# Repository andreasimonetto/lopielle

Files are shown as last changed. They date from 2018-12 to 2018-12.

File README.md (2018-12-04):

Lopielle
========

MIDI synth based on Yamaha OPLL FM synthesis sound chip (YM2413).

Made with KiCad, MPLAB-X, Inkscape, The GIMP.

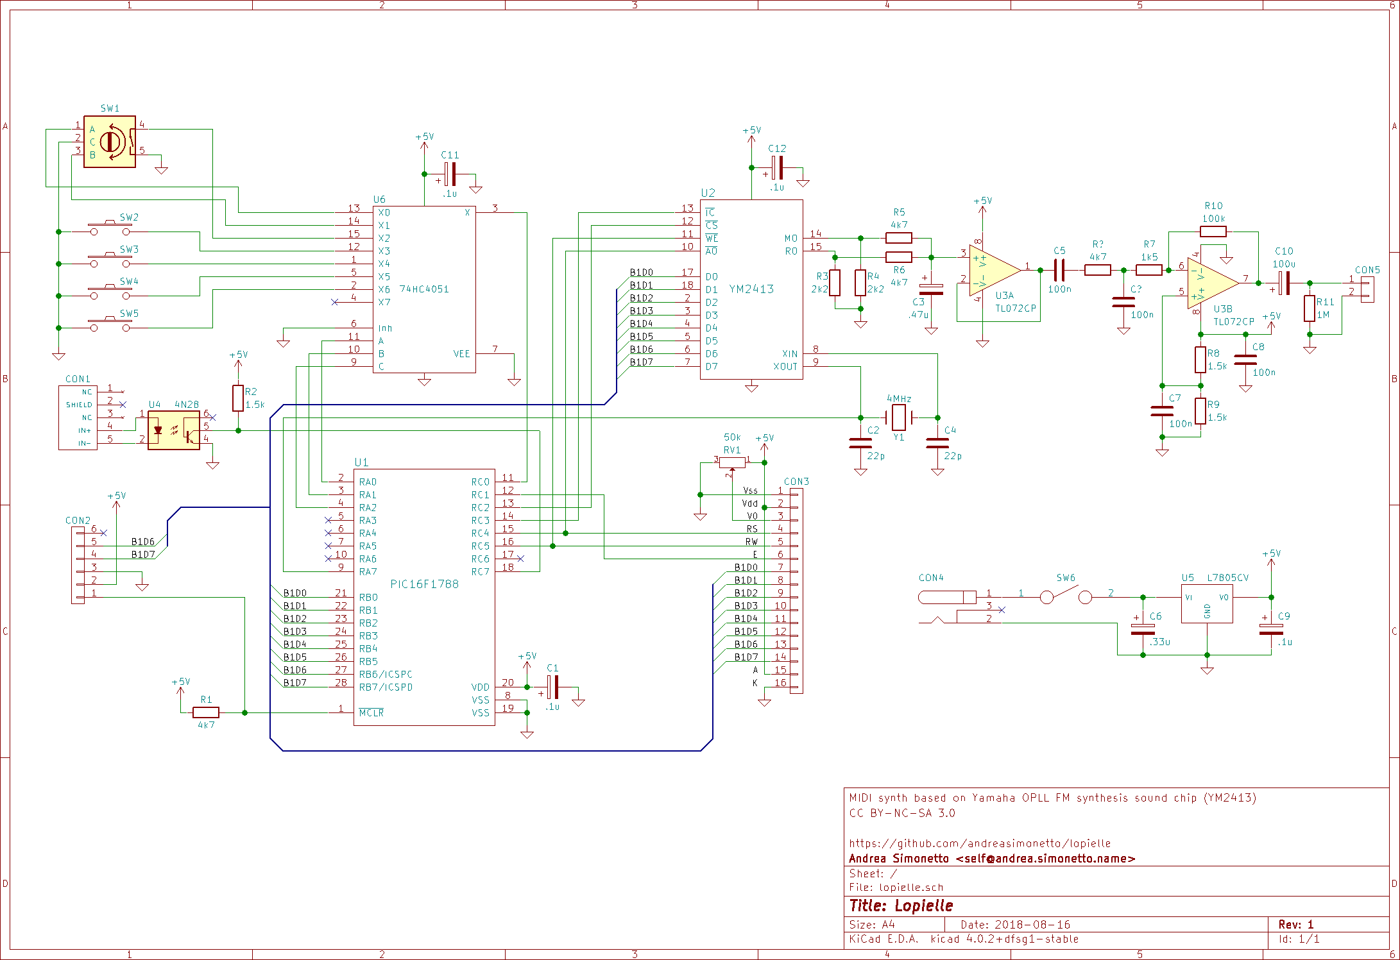
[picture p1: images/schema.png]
Electronic schematic

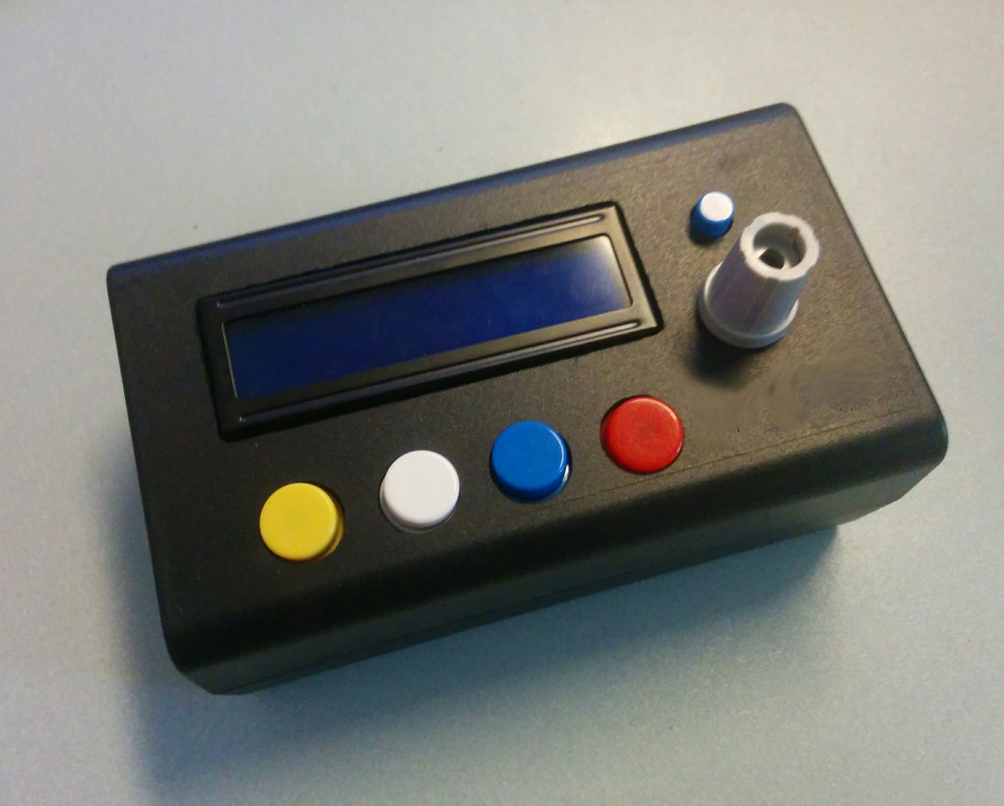
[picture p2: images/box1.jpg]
Demo product

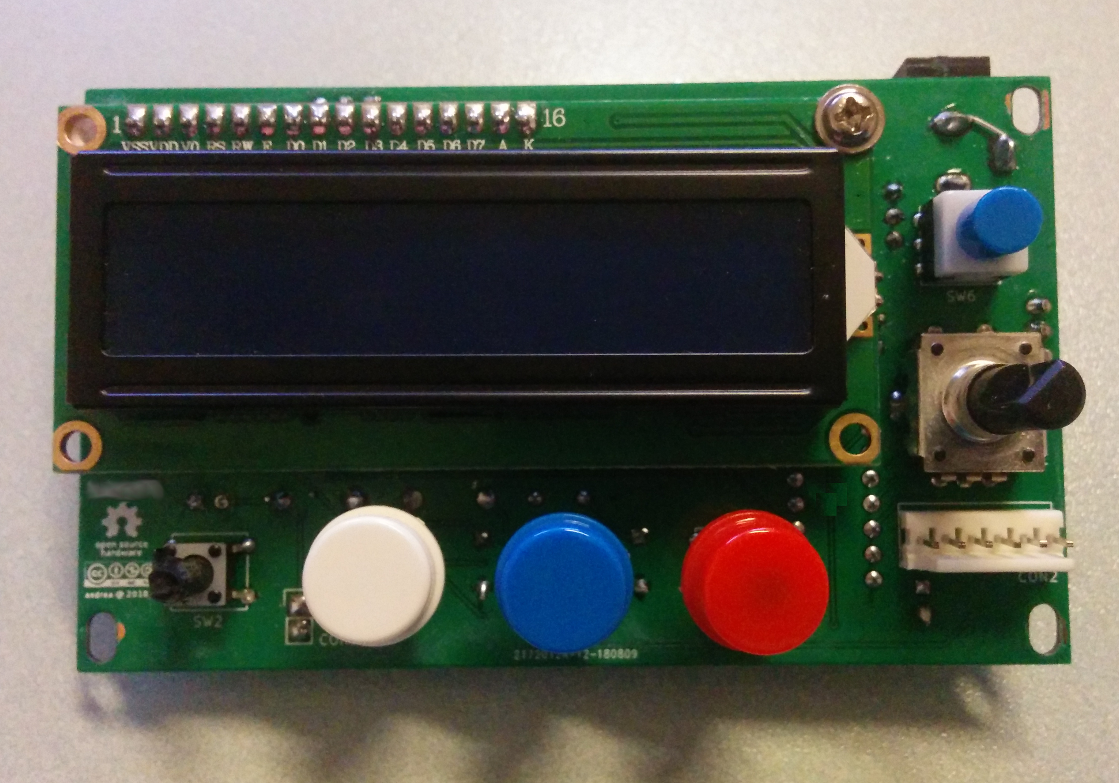
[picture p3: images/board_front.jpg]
Assembled board front

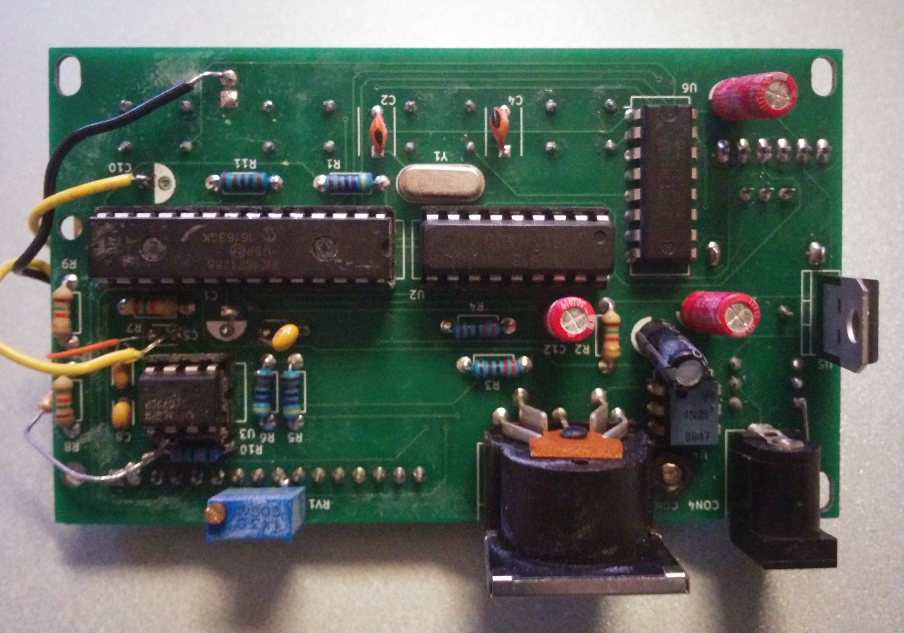
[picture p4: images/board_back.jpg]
Assembled board back

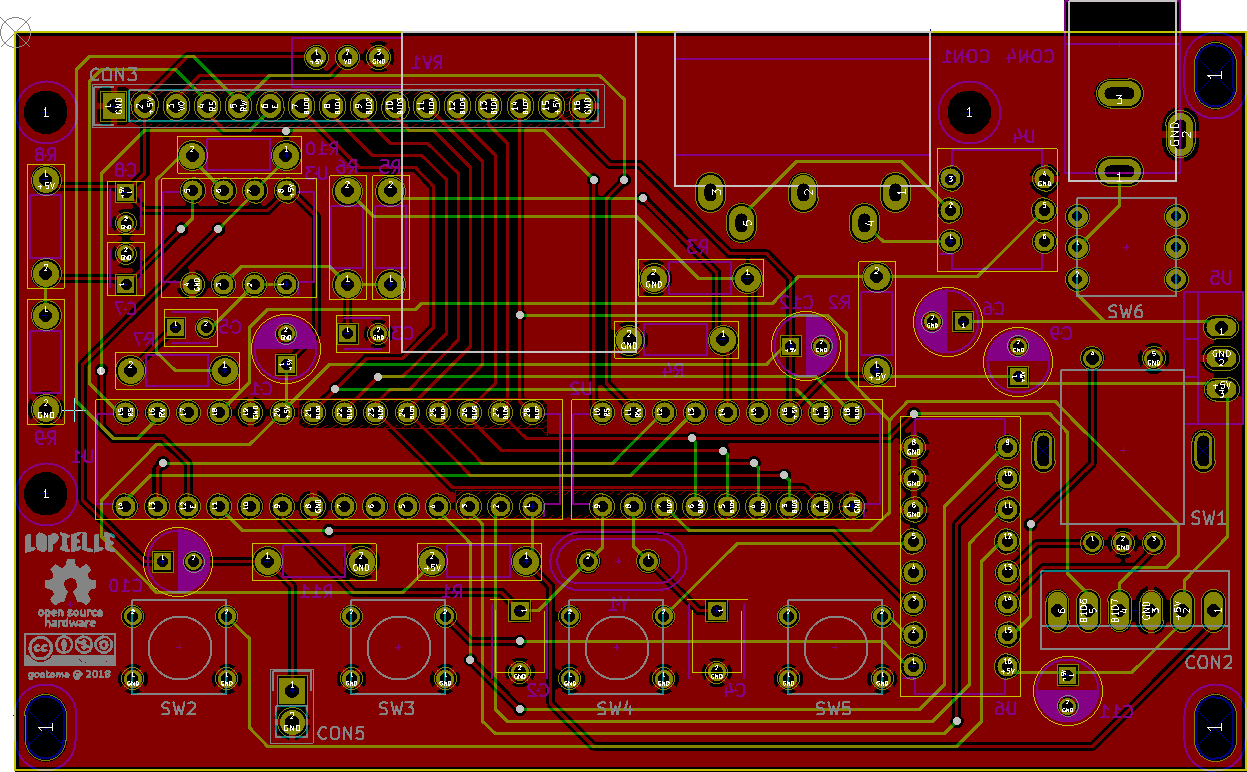
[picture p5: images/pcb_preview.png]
PCB preview


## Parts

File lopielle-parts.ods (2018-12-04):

Lopielle parts list
# | Ref. | Value | # | Ref. | Value
1 | U4 | 4N28 | 23 | C7 | 100n
2 | U6 | 74HC4051 | 24 | C2 | 22p
3 | U2 | YM2413 | 25 | C4 | 22p
4 | U1 | PIC16F1788 | 26 | C6 | .33u
5 | U3 | TL072CP | 27 | C9 | .1u
6 | SW2 | SW_PUSH | 28 | R2 | 1.5k
7 | SW5 | SW_PUSH | 29 | C3 | 100n
8 | SW3 | SW_PUSH | 30 | C8 | 100n
9 | SW4 | SW_PUSH | 31 | C5 | 100n
10 | Y1 | 4MHz | 32 | R1 | 4k7
11 | SW1 | Rotary_Encoder_Switch | 33 | C1 | .1u
12 | RV1 | 50k | 34 | CON1 | MIDI_In
13 | R5 | 4k7 | 35 | CON4 | BARREL_JACK
14 | R6 | 4k7 | 36 | CON5 | CONN_01X02
15 | R3 | 2k2 | 37 | CON3 | CONN_01X16
16 | R4 | 2k2 | 38 | CON2 | CONN_01X06
17 | R7 | 1k5 | 39 | C11 | .1u
18 | R10 | 100k | 40 | C12 | .1u
19 | C10 | 10u | 41 | U5 | L7805CV
20 | R11 | 1.5k | 42 | SW6 | SPST
21 | R8 | 1.5k
22 | R9 | 1.5k

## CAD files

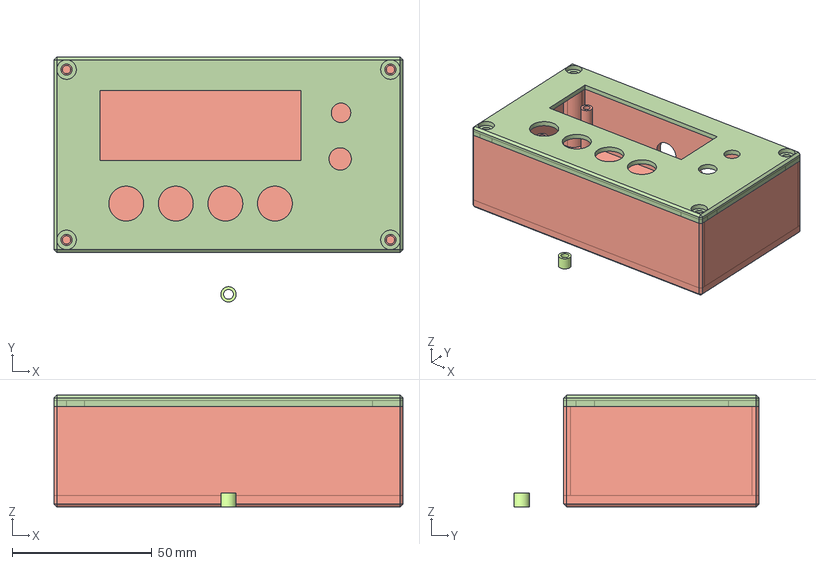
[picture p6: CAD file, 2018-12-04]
design/lopielle.fcstd
125.0 x 87.7 x 40.0 mm
Lit
Base
Spacer

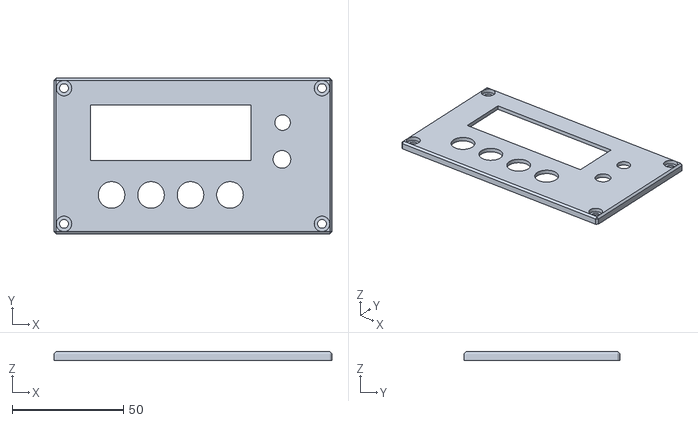
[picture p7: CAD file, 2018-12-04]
design/lopielle_lit.stl
125.0 x 70.0 x 4.00

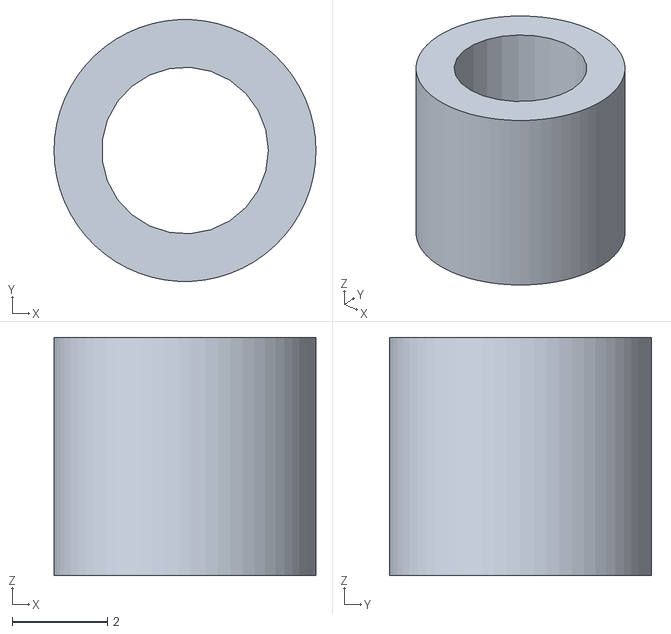
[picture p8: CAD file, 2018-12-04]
design/lopielle_spacer.stl
5.50 x 5.49 x 5.00

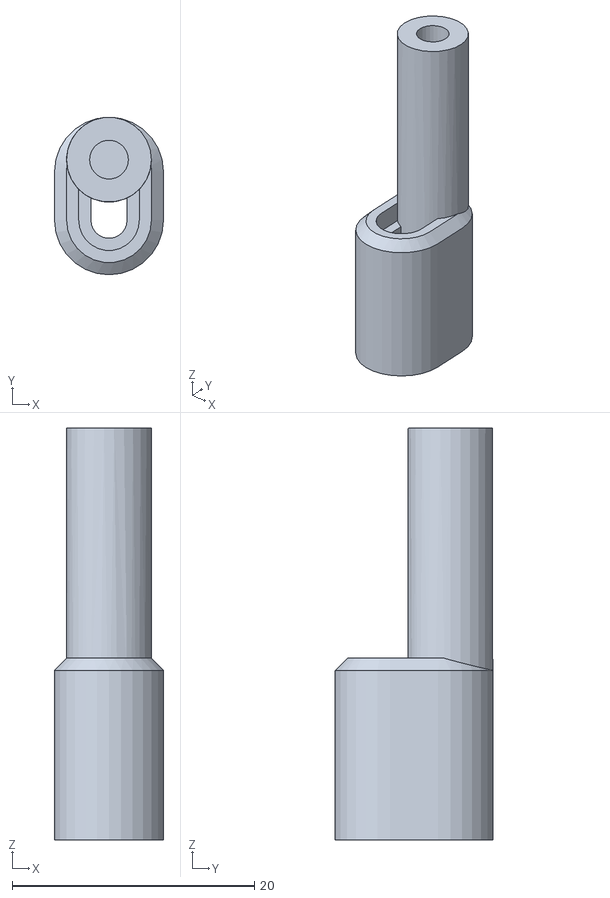
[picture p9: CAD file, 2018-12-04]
design/lopielle_support1.stl
9.00 x 13.0 x 34.0

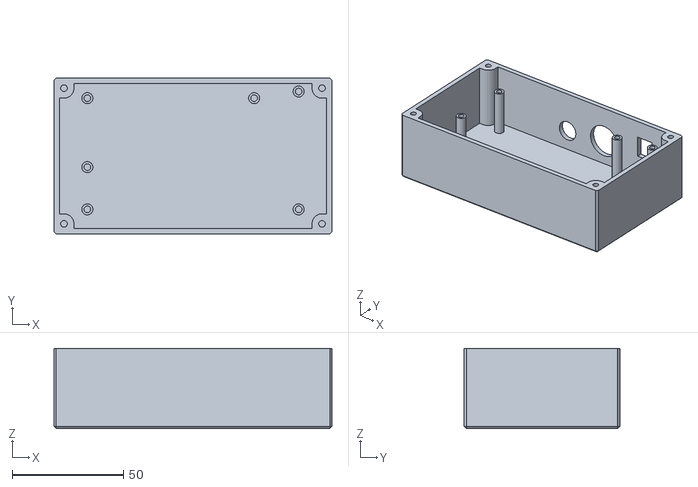
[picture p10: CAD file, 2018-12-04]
design/lopielle_base.stl
125.0 x 70.0 x 36.0

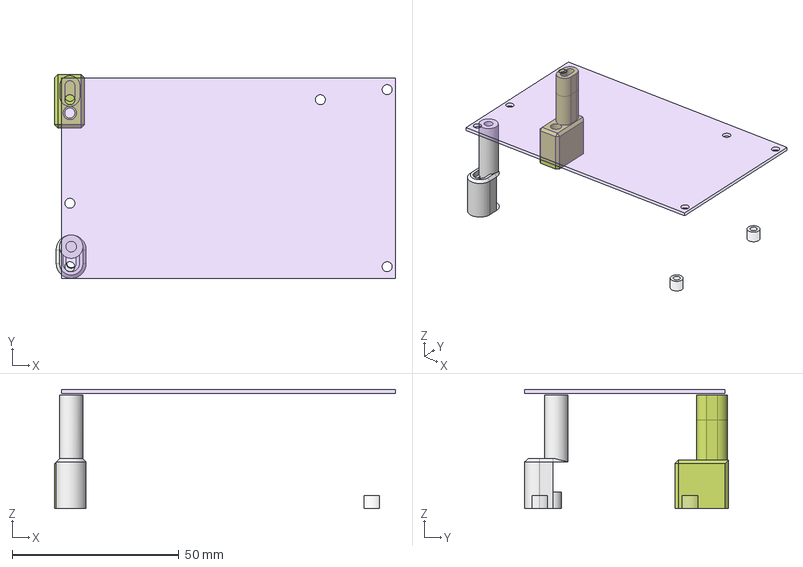
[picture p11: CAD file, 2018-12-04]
design/lopielle_supports.fcstd
102.1 x 61.0 x 35.7 mm
Cut001 (Solid)004
Cut001 (Solid)006
Cut001 (Solid)007
Cut001 (Solid)008

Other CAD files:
design/lopielle_milling.fcstd

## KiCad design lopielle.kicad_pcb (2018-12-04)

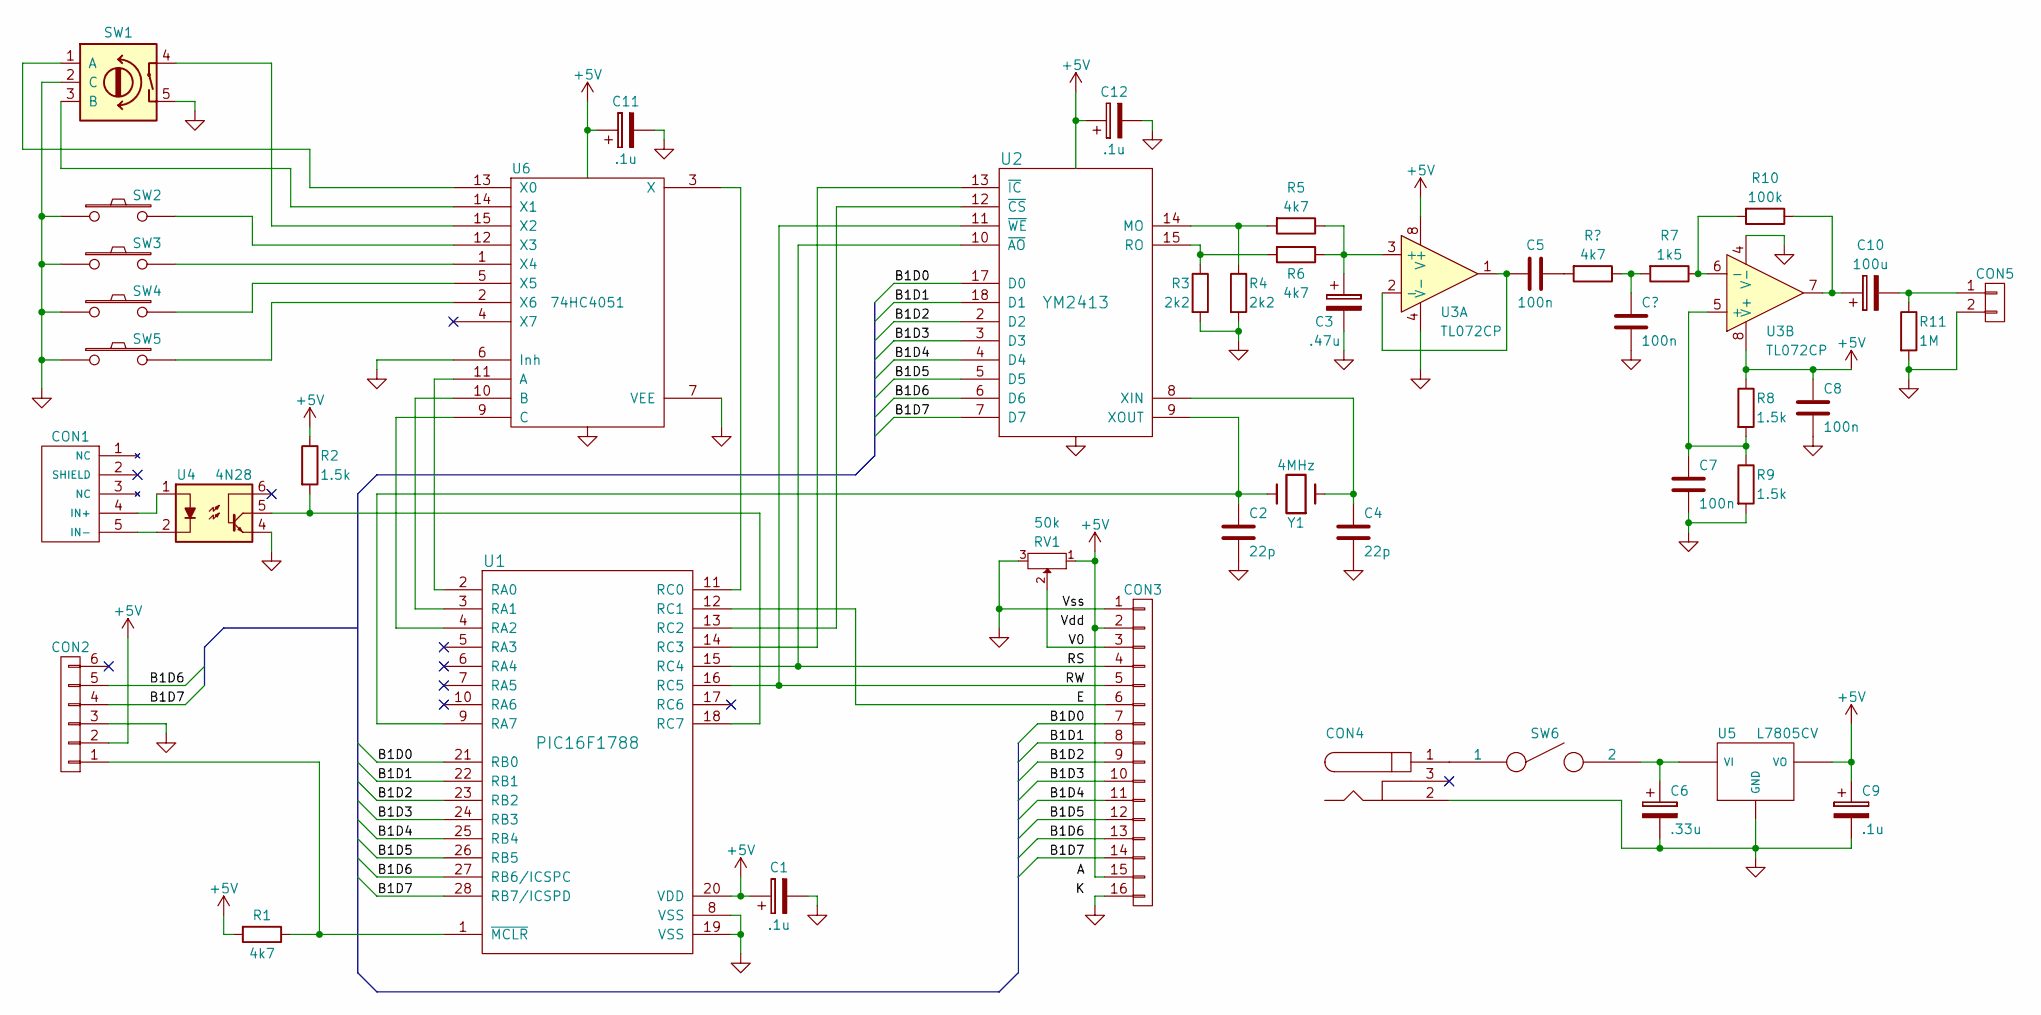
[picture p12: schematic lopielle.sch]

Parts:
C1, C9, C11, C12: .1u; C_Radial_D5_L11_P2.5
C2, C4: 22p; C_Disc_D6_P5
C3: .47u; C_Radial_D5_L11_P2.5
C5, C7, C8: 100n; C_Disc_D3_P2.5
C6: .33u; C_Radial_D5_L11_P2.5
C10: 100u; C_Radial_D5_L11_P2.5
CON1: MIDI_In; G9820_SX
CON2: CONN_01X06; PINHEAD1-6
CON3: CONN_01X16; Pin_Header_Straight_1x16
CON4: BARREL_JACK; G10560
CON5: CONN_01X02; Pin_Header_Straight_1x02
R1, R5, R6: 4k7; Resistor_Horizontal_RM7mm
R2, R8, R9: 1.5k; Resistor_Horizontal_RM7mm
R3, R4: 2k2; Resistor_Horizontal_RM7mm
R7: 1k5; Resistor_Horizontal_RM7mm
R10: 100k; Resistor_Horizontal_RM7mm
R11: 1M; Resistor_Horizontal_RM7mm
RV1: 50k; Trimmer_ACP
SW1: Rotary_Encoder_Switch; PEC12R-4222F-S0024
SW2, SW3, SW4, SW5: SW_PUSH; SW_PUSH_SMALL
SW6: SPST; Switch_DPDT
U1: PIC16F1788; DIP-28_W7.62mm
U2: YM2413; DIP-18_W7.62mm
U3: TL072CP; DIP-8_W7.62mm
U4: 4N28; DIP-6_W7.62mm
U5: L7805CV; TO-220_Neutral123_Vertical
U6: 74HC4051; DIP-16_W7.62mm
Y1: 4MHz; Crystal_HC49-U_Vertical

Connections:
+5V: C1.1, C8.1, C9.1, C11.1, C12.1, CON2.2, CON3.2, CON3.15, R1.2, R2.1, R8.1, RV1.1, U1.20 (VDD), U2.16 (VCC), U3.8 (V+), U5.3 (VO), U6.16 (VDD)
/B1D0: CON3.7, U1.21 (RB0), U2.17 (D0)
/B1D1: CON3.8, U1.22 (RB1), U2.18 (D1)
/B1D2: CON3.9, U1.23 (RB2), U2.2 (D2)
/B1D3: CON3.10, U1.24 (RB3), U2.3 (D3)
/B1D4: CON3.11, U1.25 (RB4), U2.4 (D4)
/B1D5: CON3.12, U1.26 (RB5), U2.5 (D5)
/B1D6: CON2.5, CON3.13, U1.27 (RB6/ICSPC), U2.6 (D6)
/B1D7: CON2.4, CON3.14, U1.28 (RB7/ICSPD), U2.7 (D7)
/E: CON3.6, U1.12 (RC1)
/RS: CON3.4, U1.15 (RC4), U2.10 (~AO)
/RW: CON3.5, U1.16 (RC5), U2.11 (~WE)
/V0: CON3.3, RV1.2
GND: C1.2, C2.2, C3.2, C4.2, C6.2, C7.2, C8.2, C9.2, C11.2, C12.2, CON2.3, CON3.1, CON3.16, CON4.2, CON5.2, R3.2, R4.2, R9.2, R11.2, RV1.3, SW1.2 (C), SW1.5, SW2.1, SW3.1, SW4.1, SW5.1, U1.8 (VSS), U1.19 (VSS), U2.1 (GND), U3.4 (V-), U4.4, U5.2 (GND), U6.6 (Inh), U6.7 (VEE), U6.8 (VSS)
unnamed: C2.1, U1.9 (RA7), U2.9 (XOUT), Y1.2
unnamed: C3.1, R5.1, R6.1, U3.3 (+)
unnamed: C4.1, U2.8 (XIN), Y1.1
unnamed: C5.1, R7.2
unnamed: C5.2, U3.1, U3.2 (-)
unnamed: C6.1, SW6.2, U5.1 (VI)
unnamed: C7.1, R8.2, R9.1, U3.5 (+)
unnamed: C10.1, R10.1, U3.7
unnamed: C10.2, CON5.1, R11.1
unnamed: CON1.4 (IN+), U4.1
unnamed: CON1.5 (IN-), U4.2
unnamed: CON2.1, R1.1, U1.1 (~MCLR)
unnamed: CON4.1, SW6.1
unnamed: R2.2, U1.18 (RC7), U4.5
unnamed: R3.1, R6.2, U2.15 (RO)
unnamed: R4.1, R5.2, U2.14 (MO)
unnamed: R7.1, R10.2, U3.6 (-)
unnamed: SW1.1 (A), U6.13 (X0)
unnamed: SW1.3 (B), U6.14 (X1)
unnamed: SW1.4, U6.15 (X2)
unnamed: SW2.2, U6.12 (X3)
unnamed: SW3.2, U6.1 (X4)
unnamed: SW4.2, U6.5 (X5)
unnamed: SW5.2, U6.2 (X6)
unnamed: U1.2 (RA0), U6.11 (A)
unnamed: U1.3 (RA1), U6.10 (B)
unnamed: U1.4 (RA2), U6.9 (C)
unnamed: U1.11 (RC0), U6.3 (X)
unnamed: U1.13 (RC2), U2.12 (~CS)
unnamed: U1.14 (RC3), U2.13 (~IC)

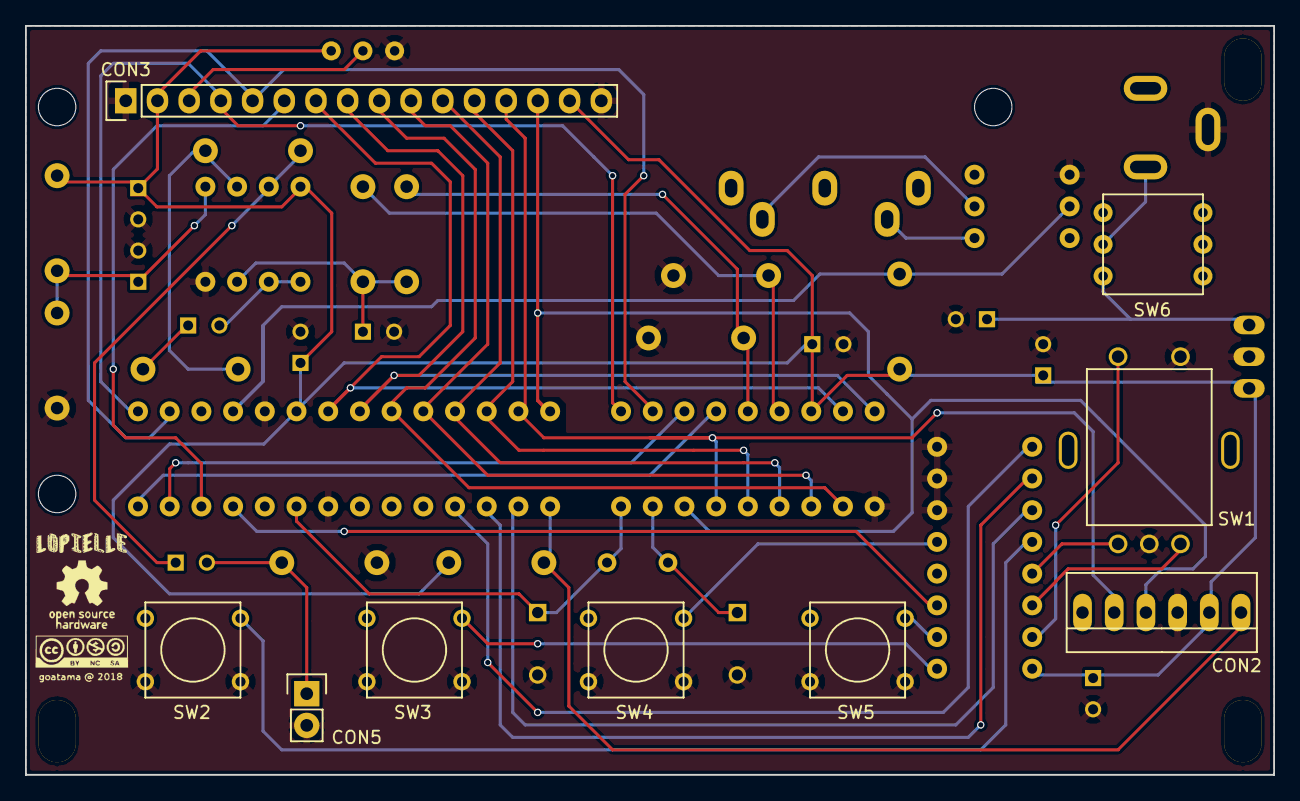
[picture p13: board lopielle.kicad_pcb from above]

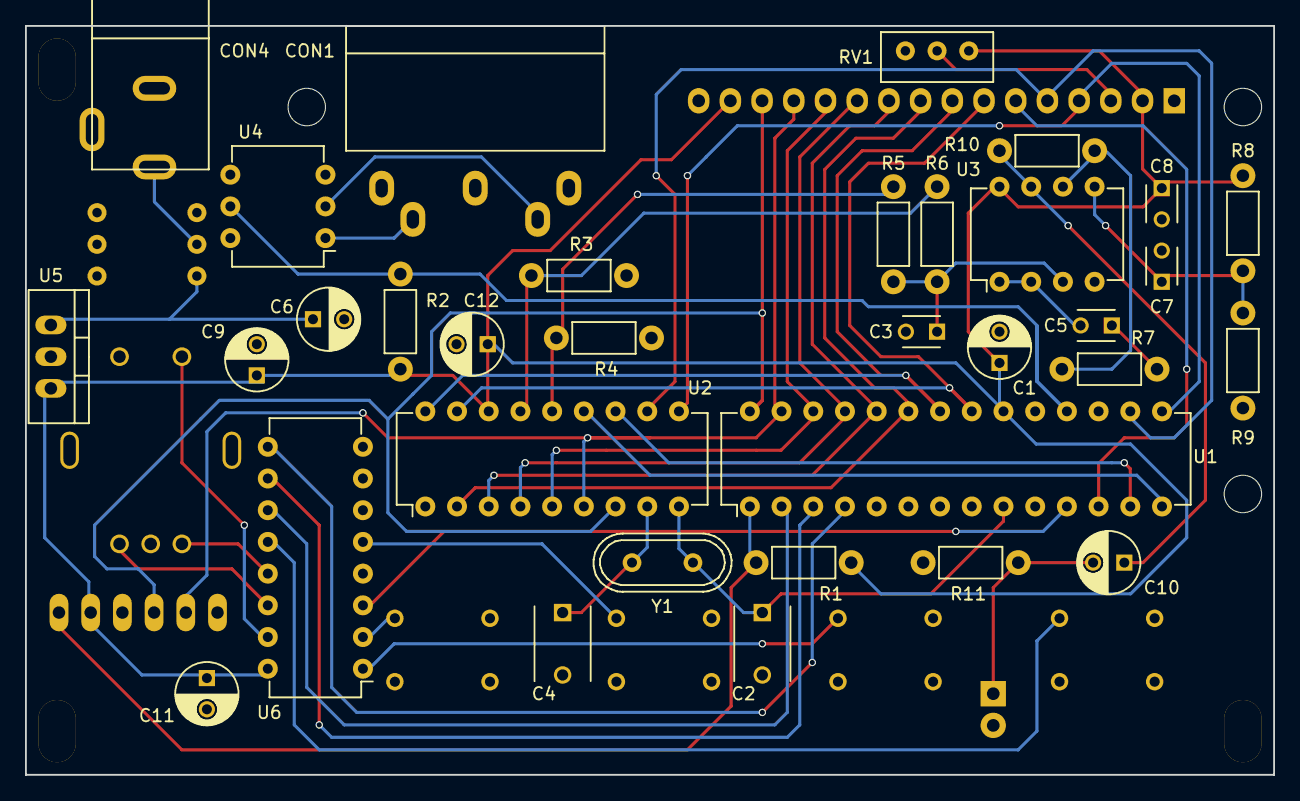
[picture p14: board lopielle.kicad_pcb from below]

Board: 2 copper layers, 100.0 x 60.0 mm, 42 parts (33 on the bottom side), 44 nets.

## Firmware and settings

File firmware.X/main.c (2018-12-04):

#include <xc.h>
#include <stdint.h>
#include <string.h>
#include "mcc_generated_files/mcc.h"

uint8_t sprintn(char* buf, uint8_t n)
{
char *p = buf;

    if(n < 10)
        goto sprintn_unit;
    else if(n < 100)
        goto sprintn_dec;

    *p++ = '0' + (n / 100);
    n %= 100;
    
    sprintn_dec:
    *p++ = '0' + (n / 10);
    n %= 10;
    
    sprintn_unit:
    *p++ = '0' + n;
    
    return (p - buf);
}

#define OPLL_ADDR_USER_TONE      0x00
#define OPLL_ADDR_RHYTHM_CTL     0x0E
#define OPLL_ADDR_TEST           0x0F
#define OPLL_ADDR_OPLL_FNUM_LSB  0x10
#define OPLL_ADDR_OPLL_FNUM_MSB  0x20
#define OPLL_ADDR_INST           0x30
#define OPLL_ADDR_RHYTHM_VOL     0x36

typedef struct {
    uint8_t am      : 1;
    uint8_t vib     : 1;
    uint8_t eg_type : 1;
    uint8_t ksr     : 1;
    uint8_t multi   : 4;
} opll_mult_factor_t;

typedef struct {
    uint8_t attack_rate : 4;
    uint8_t decay_rate  : 4;
} opll_AD_t;

typedef struct {
    uint8_t sustain_level : 4;
    uint8_t release_rate  : 4;
} opll_SR_t;

typedef struct {
    uint8_t _padding : 2;
    uint8_t sustain  : 1;
    uint8_t key      : 1;
    uint8_t block    : 3;
    uint8_t fnum     : 1;
} opll_block_t;

typedef struct {
    uint8_t inst : 4;
    uint8_t vol  : 4; // 3dB, 6dB, 12dB, 24dB
} opll_inst_t;


enum {
    OPLL_INST_USER,
    OPLL_INST_VIOLIN,
    OPLL_INST_GUITAR,
    OPLL_INST_PIANO,
    OPLL_INST_FLUTE,
    OPLL_INST_CLARINET,
    OPLL_INST_OBOE,
    OPLL_INST_TRUMPET,
    OPLL_INST_ORGAN,
    OPLL_INST_HORN,
    OPLL_INST_SYNTH,
    OPLL_INST_HARP,
    OPLL_INST_VIBRAPHONE,
    OPLL_INST_BASS_SYNTH,
    OPLL_INST_BASS_ACOUSTIC,
    OPLL_INST_GUITAR_ELECTRIC
};

const char SYNTH_INSTRUMENT_DESC[][12] = {
    "User",
    "Violin",
    "Guitar",
    "Piano",
    "Flute",
    "Clarinet",
    "Oboe",
    "Trumpet",
    "Organ",
    "Horn",
    "Synth",
    "Harp",
    "Vibraphone",
    "Bass synth",
    "Bass acoust",
    "Elec guitar"
};

// OPLL@4MHz
const uint16_t OPLL_FNUM[12] = { 154, 163, 173, 184, 194, 206, 218, 231, 245, 260, 275, 291 };

#define opll_enable() OPLL_CS_SetLow()
#define opll_disable() OPLL_CS_SetHigh()

void opll_reset(void)
{
    OPLL_WE_SetHigh();
    OPLL_CS_SetHigh();
    OPLL_IC_SetLow();
    __delay_us(20);
    OPLL_IC_SetHigh();
}

void opll_write(uint8_t addr, uint8_t val)
{
    // Address
    OPLL_A0_SetLow();
    OPLL_WE_SetLow();
    PORTB = addr;
    OPLL_CS_SetLow();
    OPLL_CS_SetHigh();
    OPLL_WE_SetHigh();
    __delay_us(3);
    
    // Data
    OPLL_A0_SetHigh();
    OPLL_WE_SetLow();
    PORTB = val;
    OPLL_CS_SetLow();
    OPLL_CS_SetHigh();
    OPLL_WE_SetHigh();
    __delay_us(12);
}

typedef struct {
    uint8_t channel;
    uint8_t instrument;
    opll_AD_t modulator_ad;
    opll_AD_t carrier_ad;
    opll_SR_t modulator_sr;
    opll_SR_t carrier_sr;
} synth_t;

enum {
    SYNTH_PARAM_CHANNEL,
    SYNTH_PARAM_INSTRUMENT,
    SYNTH_PARAM_CARRIER_ATTACK,
    SYNTH_PARAM_CARRIER_DECAY,
    SYNTH_PARAM_CARRIER_SUSTAIN,
    SYNTH_PARAM_CARRIER_RELEASE,
    SYNTH_PARAM_MODULATOR_ATTACK,
    SYNTH_PARAM_MODULATOR_DECAY,
    SYNTH_PARAM_MODULATOR_SUSTAIN,
    SYNTH_PARAM_MODULATOR_RELEASE
};

static const char SYNTH_PARAM_DESC[][13] = {
    "Channel",
    "Inst",
    "Car. attack",
    "Car. decay",
    "Car. sustain",
    "Car. release",
    "Mod. attack",
    "Mod. decay",
    "Mod. sustain",
    "Mod. release"
};

typedef struct {
    uint8_t key;
    uint8_t prio    : 4;
    uint8_t _unused : 3;
    uint8_t on      : 1;
} chan_t;

#define CHANNELS_NUM 8

static chan_t chan[CHANNELS_NUM];
static synth_t synth = { 0, OPLL_INST_PIANO };

void opll_play(uint8_t key, uint8_t vel)
{
uint16_t n;
uint8_t i, ch, oct;

    if(key >= 12)
        key -= 12;

    n = OPLL_FNUM[key % 12];

    oct = key / 12;
    if(oct > 7)
        oct = 7;    
    oct = (oct << 1) | (n >> 8);
    
    vel >>= 3;

    for(ch = 0; ch < CHANNELS_NUM; ++ch) {
        if(chan[ch].key == key)
            break;
    }
    
    if(vel) {
        if(ch == CHANNELS_NUM) {
            for(ch = 0; ch < CHANNELS_NUM; ++ch) {
                if(!chan[ch].prio)
                    break;
            }
        }
        
        chan[ch].on = 1;
        chan[ch].key = key;
        
        opll_write(OPLL_ADDR_OPLL_FNUM_MSB + ch, 0);
        opll_write(OPLL_ADDR_INST + ch, (synth.instrument << 4) | (~vel & 0xf));
        opll_write(OPLL_ADDR_OPLL_FNUM_LSB + ch, (uint8_t)n);
        opll_write(OPLL_ADDR_OPLL_FNUM_MSB + ch, 0x10 | oct);
        
        for(i = 0; i < CHANNELS_NUM; ++i) {
            if(chan[i].prio)
                --chan[i].prio;
        }
    }
    else if(ch != CHANNELS_NUM && chan[ch].on) {
        for(i = 0; i < CHANNELS_NUM; ++i) {
            if(chan[i].prio > chan[ch].prio)
                --chan[i].prio;
        }

        chan[ch].on = 0;
        
        opll_write(OPLL_ADDR_OPLL_FNUM_MSB + ch, 0x00 | oct);
    }
    else
        return;
    
    chan[ch].prio = CHANNELS_NUM - 1;
}






#define DPY_FRAMEBUF_SIZE 32

static volatile char dpy_framebuf[DPY_FRAMEBUF_SIZE] = {
    ' ', ' ', ' ', ' ', 'L', 'a', 'z', 'y', ' ', '\'', '8', '8', ' ', ' ', ' ', ' ', 
    ' ', 'a', 's', 'd', 'r', 'e', 'a', ' ', '@', ' ', '2', '0', '1', '8', ' ', 0xbc
};
static volatile uint8_t dpy_need_update = 0;

void dpy_write_instruction(uint8_t x)
{
    OPLL_WE_SetLow(); // RW: Write
    OPLL_A0_SetLow(); // RS: Instruction
    LATB = x;
    DPY_CS_SetHigh();
    NOP(); NOP(); NOP(); NOP(); NOP();
    DPY_CS_SetLow();
    OPLL_WE_SetHigh(); // RW: Read (default)
    __delay_us(1);
}

void dpy_write_data(uint8_t x)
{
    OPLL_WE_SetLow(); // RW: Write
    OPLL_A0_SetHigh(); // RS: Data
    LATB = x;
    DPY_CS_SetHigh();
    NOP(); NOP(); NOP(); NOP(); NOP();
    DPY_CS_SetLow();
    OPLL_WE_SetHigh(); // RW: Read (default)
    __delay_us(1);
}

void dpy_reset(void)
{
    dpy_write_instruction(0x3f);
    __delay_us(37);

    dpy_write_instruction(0x01);
    __delay_ms(2);
    
    dpy_write_instruction(0x0c);
    __delay_us(37);
}

void dpy_cursor_show()
{
    dpy_write_instruction(0x0d);
    __delay_us(37);
}

void dpy_cursor_hide()
{
    dpy_write_instruction(0x0c);
    __delay_us(37);
}

void dpy_cursor_move(uint8_t row, uint8_t col)
{
    dpy_write_instruction(0x80 | (40 * row + col));
    __delay_us(37);
}

void dpy_update()
{
uint8_t i;
char c;

    dpy_write_instruction(0x80);
    __delay_us(37);
    for(i = 0; i < 16; ++i) {
        if(!(c = dpy_framebuf[i]))
            c = ' ';
        dpy_write_data(c);
        __delay_us(37);
    }

    dpy_write_instruction(0xa8);
    __delay_us(37);
    for(; i < 32; ++i) {
        if(!(c = dpy_framebuf[i]))
            c = ' ';
        dpy_write_data(c);
        __delay_us(37);
    }
}













enum {
    CTL_ENCODER_A       = 0x01,
    CTL_ENCODER_B       = 0x02,
    CTL_ENCODER_BUTTON  = 0x04,
    CTL_BUTTON1         = 0x08,
    CTL_BUTTON2         = 0x10,
    CTL_BUTTON3         = 0x20,
    CTL_BUTTON4         = 0x40
};

static volatile uint8_t ctl_status_prev, ctl_status;
static volatile uint8_t button_press_ms[4];

#define ctl_changed(ctl) ((ctl_status & (ctl)) != (ctl_status_prev & (ctl)))
#define ctl_button_isup(ctl) (ctl_status & (ctl))
#define ctl_button_isdown(ctl) (!ctl_button_isup(ctl))
#define ctl_button_released(ctl) (ctl_changed(ctl) && ctl_button_isup(ctl))
#define ctl_button_pressed(ctl) (ctl_changed(ctl) && ctl_button_isdown(ctl))

void ctl_status_update(void)
{
uint8_t i;

    ctl_status = 0;
    for(i = 0; i < 8; ++i) {
        LATA = (LATA & 0xf8) | i;
        NOP(); NOP(); NOP(); NOP();
        ctl_status |= (CTL_DATA_GetValue() << i);
    }
}

void ctl_status_reset(void)
{
    ctl_status_update();
    ctl_status_prev = ctl_status;
}

extern volatile uint8_t timer0ReloadVal;

static volatile uint8_t synth_param_cur = 0;
static volatile uint8_t synth_param_editing = 0;

#define SYNTH_PARAMS_NUM 10


















uint8_t synth_param_change(uint8_t param, int8_t amount)
{
uint8_t d;

    switch(param) {
        case SYNTH_PARAM_CHANNEL:
            d = synth.channel + amount;
            if(d >= 16)
                return 0;
            synth.channel = d;
            return 1;

        case SYNTH_PARAM_INSTRUMENT:
            d = synth.instrument + amount;
            if(d >= 16)
                return 0;
            synth.instrument = d;
            return 1;

        case SYNTH_PARAM_CARRIER_ATTACK:
            d = synth.carrier_ad.attack_rate + amount;
            if(d >= 16)
                return 0;
            synth.carrier_ad.attack_rate = d;
            return 1;

        case SYNTH_PARAM_CARRIER_DECAY:
            d = synth.carrier_ad.decay_rate + amount;
            if(d >= 16)
                return 0;
            synth.carrier_ad.decay_rate = d;
            return 1;

        case SYNTH_PARAM_CARRIER_SUSTAIN:
            d = synth.carrier_sr.sustain_level + amount;
            if(d >= 16)
                return 0;
            synth.carrier_sr.sustain_level = d;
            return 1;

        case SYNTH_PARAM_CARRIER_RELEASE:
            d = synth.carrier_sr.release_rate + amount;
            if(d >= 16)
                return 0;
            synth.carrier_sr.release_rate = d;
            return 1;

        case SYNTH_PARAM_MODULATOR_ATTACK:
            d = synth.modulator_ad.attack_rate + amount;
            if(d >= 16)
                return 0;
            synth.modulator_ad.attack_rate = d;
            return 1;

        case SYNTH_PARAM_MODULATOR_DECAY:
            d = synth.modulator_ad.decay_rate + amount;
            if(d >= 16)
                return 0;
            synth.modulator_ad.decay_rate = d;
            return 1;
            
        case SYNTH_PARAM_MODULATOR_SUSTAIN:
            d = synth.modulator_sr.sustain_level + amount;
            if(d >= 16)
                return 0;
            synth.modulator_sr.sustain_level = d;
            return 1;

        case SYNTH_PARAM_MODULATOR_RELEASE:
            d = synth.modulator_sr.release_rate + amount;
            if(d >= 16)
                return 0;
            synth.modulator_sr.release_rate = d;
            return 1;
    }
    
    return 0;
}

uint8_t synth_param_snprint(char* buf, uint8_t buf_len, uint8_t param)
{
uint8_t d1, d2;
const char *desc = SYNTH_PARAM_DESC[param];
uint8_t d = strlen(desc);

    memcpy(buf, desc, d);
    buf[d++] = ' ';
    d1 = d;
    
    switch(param) {
        case SYNTH_PARAM_CHANNEL:
            d += sprintn(buf + d, synth.channel);
            break;

        case SYNTH_PARAM_INSTRUMENT:
            desc = SYNTH_INSTRUMENT_DESC[synth.instrument];
            d2 = strlen(desc);
            memcpy(buf + d, desc, d2);
            d += d2;
            break;

        case SYNTH_PARAM_CARRIER_ATTACK:
            d += sprintn(buf + d, synth.carrier_ad.attack_rate);
            break;

        case SYNTH_PARAM_CARRIER_DECAY:
            d += sprintn(buf + d, synth.carrier_ad.decay_rate);
            break;

        case SYNTH_PARAM_CARRIER_SUSTAIN:
            d += sprintn(buf + d, synth.carrier_sr.sustain_level);
            break;

        case SYNTH_PARAM_CARRIER_RELEASE:
            d += sprintn(buf + d, synth.carrier_sr.release_rate);
            break;

        case SYNTH_PARAM_MODULATOR_ATTACK:
            d += sprintn(buf + d, synth.modulator_ad.attack_rate);
            break;

        case SYNTH_PARAM_MODULATOR_DECAY:
            d += sprintn(buf + d, synth.modulator_ad.decay_rate);
            break;

        case SYNTH_PARAM_MODULATOR_SUSTAIN:
            d += sprintn(buf + d, synth.modulator_sr.sustain_level);
            break;

        case SYNTH_PARAM_MODULATOR_RELEASE:
            d += sprintn(buf + d, synth.modulator_sr.release_rate);
            break;
    }
    
    while(d < buf_len)
        buf[d++] = ' ';
    return d1;
}

void TMR0_ISR(void)
{
int8_t ctl_encoder_dir = 0;
uint8_t i;

    INTCONbits.TMR0IF = 0;
    TMR0 = timer0ReloadVal;

    ctl_status_prev = ctl_status;
    ctl_status_update();
    
    for(i = 0; i < 4; ++i) {
        if(!button_press_ms[i])
            continue;
        ++button_press_ms[i];
    }

    if((ctl_changed(CTL_ENCODER_A) || ctl_changed(CTL_ENCODER_B)) && (ctl_status & 0x3) == 0) {
        if((ctl_status_prev & 0x3) == 1)
            ctl_encoder_dir = -1;
        else if((ctl_status_prev & 0x3) == 2)
            ctl_encoder_dir = 1;
    }
    
    if(ctl_encoder_dir) {
        if(synth_param_editing) {
            if(synth_param_change(synth_param_cur, ctl_encoder_dir))
                dpy_need_update = 1;
        }
        else if((ctl_encoder_dir > 0 && synth_param_cur < (SYNTH_PARAMS_NUM - 1)) || (ctl_encoder_dir < 0 && synth_param_cur > 0)) {
            synth_param_cur += ctl_encoder_dir;
            dpy_need_update = 1;
        }
    }
    
    if(ctl_button_pressed(CTL_ENCODER_BUTTON)) {
        synth_param_editing = !synth_param_editing;
        dpy_need_update = 1;
    }
        
    if(ctl_button_pressed(CTL_BUTTON1)) {
        button_press_ms[0] = 1;
    }
    else if(ctl_button_released(CTL_BUTTON1)) {
        button_press_ms[0] = 0;
    }
}
  
//void PIN_MANAGER_IOC(void)
//{   
//	// Interrupt on change for pin PWR_BTN
//    if(IOCAFbits.IOCAF5) {
//        AMP_OE_SetDigitalOutput();
//        AMP_PWR_SetLow();
//        IOCAFbits.IOCAF5 = 0;
//    }	
//}


void main(void)
{
uint8_t msg = 0, midi_data_len = 0;
uint8_t d, cur_col, midi_data[8];

    SYSTEM_Initialize();
    __delay_ms(5);

    AMP_PWR_SetHigh();
    
    dpy_reset();
    dpy_update();
    __delay_ms(1000);
    dpy_need_update = 1;
    
    opll_reset();
    ctl_status_reset();
    
    AMP_OE_SetDigitalInput();
    IOCAFbits.IOCAF5 = 0;
    
    INTERRUPT_GlobalInterruptEnable();
    INTERRUPT_PeripheralInterruptEnable();

    //opll_write(0, 0x20);
    //opll_write(1, 0x20);
    //opll_write(6, 0xf0);
    //opll_write(7, 0xf0);
    
    while(1) {
        if(dpy_need_update) {
            cur_col = synth_param_snprint((char*)dpy_framebuf, DPY_FRAMEBUF_SIZE / 2, synth_param_cur);
            if(!synth_param_editing)
                cur_col = 0;
            
            if(synth_param_cur < (SYNTH_PARAMS_NUM - 1))
                synth_param_snprint((char*)dpy_framebuf + DPY_FRAMEBUF_SIZE / 2, DPY_FRAMEBUF_SIZE / 2, synth_param_cur + 1);
            else
                memset((void*)(dpy_framebuf + DPY_FRAMEBUF_SIZE / 2), ' ', DPY_FRAMEBUF_SIZE / 2);

            dpy_cursor_hide();
            dpy_update();
            dpy_cursor_move(0, cur_col);
            dpy_cursor_show();
            dpy_need_update = 0;
            
            opll_write(0x2, 36);
            opll_write(0x3, 41);
            opll_write(0x4, *((uint8_t*)&synth.modulator_ad));
            opll_write(0x5, *((uint8_t*)&synth.carrier_ad));
            opll_write(0x6, *((uint8_t*)&synth.modulator_sr));
            opll_write(0x7, *((uint8_t*)&synth.carrier_sr));
        }
            
        if(!EUSART_is_rx_ready())
            continue;

        d = EUSART_Read();
        if((d >> 7)) {
            midi_data_len = 0;
            
            if((d & 0xf) == synth.channel)
                msg = (d >> 4);
            else
                msg = 0;

            continue;
        }
        
        midi_data[midi_data_len++] = d;

        switch(msg) {
            case 0b1000: // Note off
                if(midi_data_len != 2)
                    break;

                opll_play(midi_data[0], 0);
                midi_data_len = 0;
                break;
            case 0b1001: // Note on
                if(midi_data_len != 2)
                    break;

                opll_play(midi_data[0], midi_data[1]);
                midi_data_len = 0;
                break;
        }
    }
}

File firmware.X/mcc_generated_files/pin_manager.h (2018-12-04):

/**
  @Generated Pin Manager Header File

  @Company:
    Microchip Technology Inc.

  @File Name:
    pin_manager.h

  @Summary:
    This is the Pin Manager file generated using PIC10 / PIC12 / PIC16 / PIC18 MCUs

  @Description
    This header file provides APIs for driver for .
    Generation Information :
        Product Revision  :  PIC10 / PIC12 / PIC16 / PIC18 MCUs - 1.65.2
        Device            :  PIC16F1788
        Driver Version    :  2.01
    The generated drivers are tested against the following:
        Compiler          :  XC8 1.45
        MPLAB 	          :  MPLAB X 4.15	
*/

/*
    (c) 2018 Microchip Technology Inc. and its subsidiaries. 
    
    Subject to your compliance with these terms, you may use Microchip software and any 
    derivatives exclusively with Microchip products. It is your responsibility to comply with third party 
    license terms applicable to your use of third party software (including open source software) that 
    may accompany Microchip software.
    
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
    IN NO EVENT WILL MICROCHIP BE LIABLE FOR ANY INDIRECT, SPECIAL, PUNITIVE, 
    INCIDENTAL OR CONSEQUENTIAL LOSS, DAMAGE, COST OR EXPENSE OF ANY KIND 
    WHATSOEVER RELATED TO THE SOFTWARE, HOWEVER CAUSED, EVEN IF MICROCHIP 
    HAS BEEN ADVISED OF THE POSSIBILITY OR THE DAMAGES ARE FORESEEABLE. TO 
    THE FULLEST EXTENT ALLOWED BY LAW, MICROCHIP'S TOTAL LIABILITY ON ALL 
    CLAIMS IN ANY WAY RELATED TO THIS SOFTWARE WILL NOT EXCEED THE AMOUNT 
    OF FEES, IF ANY, THAT YOU HAVE PAID DIRECTLY TO MICROCHIP FOR THIS 
    SOFTWARE.
*/

#ifndef PIN_MANAGER_H
#define PIN_MANAGER_H

#define INPUT   1
#define OUTPUT  0

#define HIGH    1
#define LOW     0

#define ANALOG      1
#define DIGITAL     0

#define PULL_UP_ENABLED      1
#define PULL_UP_DISABLED     0

// get/set CTL_A0 aliases
#define CTL_A0_TRIS                 TRISAbits.TRISA0
#define CTL_A0_LAT                  LATAbits.LATA0
#define CTL_A0_PORT                 PORTAbits.RA0
#define CTL_A0_WPU                  WPUAbits.WPUA0
#define CTL_A0_ANS                  ANSELAbits.ANSA0
#define CTL_A0_SetHigh()            do { LATAbits.LATA0 = 1; } while(0)
#define CTL_A0_SetLow()             do { LATAbits.LATA0 = 0; } while(0)
#define CTL_A0_Toggle()             do { LATAbits.LATA0 = ~LATAbits.LATA0; } while(0)
#define CTL_A0_GetValue()           PORTAbits.RA0
#define CTL_A0_SetDigitalInput()    do { TRISAbits.TRISA0 = 1; } while(0)
#define CTL_A0_SetDigitalOutput()   do { TRISAbits.TRISA0 = 0; } while(0)
#define CTL_A0_SetPullup()          do { WPUAbits.WPUA0 = 1; } while(0)
#define CTL_A0_ResetPullup()        do { WPUAbits.WPUA0 = 0; } while(0)
#define CTL_A0_SetAnalogMode()      do { ANSELAbits.ANSA0 = 1; } while(0)
#define CTL_A0_SetDigitalMode()     do { ANSELAbits.ANSA0 = 0; } while(0)

// get/set CTL_A1 aliases
#define CTL_A1_TRIS                 TRISAbits.TRISA1
#define CTL_A1_LAT                  LATAbits.LATA1
#define CTL_A1_PORT                 PORTAbits.RA1
#define CTL_A1_WPU                  WPUAbits.WPUA1
#define CTL_A1_ANS                  ANSELAbits.ANSA1
#define CTL_A1_SetHigh()            do { LATAbits.LATA1 = 1; } while(0)
#define CTL_A1_SetLow()             do { LATAbits.LATA1 = 0; } while(0)
#define CTL_A1_Toggle()             do { LATAbits.LATA1 = ~LATAbits.LATA1; } while(0)
#define CTL_A1_GetValue()           PORTAbits.RA1
#define CTL_A1_SetDigitalInput()    do { TRISAbits.TRISA1 = 1; } while(0)
#define CTL_A1_SetDigitalOutput()   do { TRISAbits.TRISA1 = 0; } while(0)
#define CTL_A1_SetPullup()          do { WPUAbits.WPUA1 = 1; } while(0)
#define CTL_A1_ResetPullup()        do { WPUAbits.WPUA1 = 0; } while(0)
#define CTL_A1_SetAnalogMode()      do { ANSELAbits.ANSA1 = 1; } while(0)
#define CTL_A1_SetDigitalMode()     do { ANSELAbits.ANSA1 = 0; } while(0)

// get/set CTL_A2 aliases
#define CTL_A2_TRIS                 TRISAbits.TRISA2
#define CTL_A2_LAT                  LATAbits.LATA2
#define CTL_A2_PORT                 PORTAbits.RA2
#define CTL_A2_WPU                  WPUAbits.WPUA2
#define CTL_A2_ANS                  ANSELAbits.ANSA2
#define CTL_A2_SetHigh()            do { LATAbits.LATA2 = 1; } while(0)
#define CTL_A2_SetLow()             do { LATAbits.LATA2 = 0; } while(0)
#define CTL_A2_Toggle()             do { LATAbits.LATA2 = ~LATAbits.LATA2; } while(0)
#define CTL_A2_GetValue()           PORTAbits.RA2
#define CTL_A2_SetDigitalInput()    do { TRISAbits.TRISA2 = 1; } while(0)
#define CTL_A2_SetDigitalOutput()   do { TRISAbits.TRISA2 = 0; } while(0)
#define CTL_A2_SetPullup()          do { WPUAbits.WPUA2 = 1; } while(0)
#define CTL_A2_ResetPullup()        do { WPUAbits.WPUA2 = 0; } while(0)
#define CTL_A2_SetAnalogMode()      do { ANSELAbits.ANSA2 = 1; } while(0)
#define CTL_A2_SetDigitalMode()     do { ANSELAbits.ANSA2 = 0; } while(0)

// get/set AMP_PWR aliases
#define AMP_PWR_TRIS                 TRISAbits.TRISA3
#define AMP_PWR_LAT                  LATAbits.LATA3
#define AMP_PWR_PORT                 PORTAbits.RA3
#define AMP_PWR_WPU                  WPUAbits.WPUA3
#define AMP_PWR_ANS                  ANSELAbits.ANSA3
#define AMP_PWR_SetHigh()            do { LATAbits.LATA3 = 1; } while(0)
#define AMP_PWR_SetLow()             do { LATAbits.LATA3 = 0; } while(0)
#define AMP_PWR_Toggle()             do { LATAbits.LATA3 = ~LATAbits.LATA3; } while(0)
#define AMP_PWR_GetValue()           PORTAbits.RA3
#define AMP_PWR_SetDigitalInput()    do { TRISAbits.TRISA3 = 1; } while(0)
#define AMP_PWR_SetDigitalOutput()   do { TRISAbits.TRISA3 = 0; } while(0)
#define AMP_PWR_SetPullup()          do { WPUAbits.WPUA3 = 1; } while(0)
#define AMP_PWR_ResetPullup()        do { WPUAbits.WPUA3 = 0; } while(0)
#define AMP_PWR_SetAnalogMode()      do { ANSELAbits.ANSA3 = 1; } while(0)
#define AMP_PWR_SetDigitalMode()     do { ANSELAbits.ANSA3 = 0; } while(0)

// get/set AMP_OE aliases
#define AMP_OE_TRIS                 TRISAbits.TRISA4
#define AMP_OE_LAT                  LATAbits.LATA4
#define AMP_OE_PORT                 PORTAbits.RA4
#define AMP_OE_WPU                  WPUAbits.WPUA4
#define AMP_OE_ANS                  ANSELAbits.ANSA4
#define AMP_OE_SetHigh()            do { LATAbits.LATA4 = 1; } while(0)
#define AMP_OE_SetLow()             do { LATAbits.LATA4 = 0; } while(0)
#define AMP_OE_Toggle()             do { LATAbits.LATA4 = ~LATAbits.LATA4; } while(0)
#define AMP_OE_GetValue()           PORTAbits.RA4
#define AMP_OE_SetDigitalInput()    do { TRISAbits.TRISA4 = 1; } while(0)
#define AMP_OE_SetDigitalOutput()   do { TRISAbits.TRISA4 = 0; } while(0)
#define AMP_OE_SetPullup()          do { WPUAbits.WPUA4 = 1; } while(0)
#define AMP_OE_ResetPullup()        do { WPUAbits.WPUA4 = 0; } while(0)
#define AMP_OE_SetAnalogMode()      do { ANSELAbits.ANSA4 = 1; } while(0)
#define AMP_OE_SetDigitalMode()     do { ANSELAbits.ANSA4 = 0; } while(0)
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

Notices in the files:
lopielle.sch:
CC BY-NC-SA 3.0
